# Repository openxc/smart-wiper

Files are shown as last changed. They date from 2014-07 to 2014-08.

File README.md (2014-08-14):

**Smart Wiper**
===============

The Smart Wiper project provides a simple way for collecting data on rain frequency and/or intensity. A 3D printed enclosure or 'box' houses an inertial measurement unit that can be attached to the windshield wiper. The device monitors the change in acceleration of the windshield wiper and use that as a surrogate for rain detection and intensity. 
The project contains:

* [Electronics Layout](https://github.com/openxc/smart-wiper/tree/master/Circuit_Design): The circuit diagram and all necessary electronics for the box
* [Arduino Firmware](https://github.com/openxc/smart-wiper/tree/master/Arduino): The arduino firmware that converts acceleration data into a generic wiper movement data
* [Android Project](https://github.com/openxc/smart-wiper/tree/master/Android): That communicates with the electronics box over bluetooth and provides a simple UI to display that
* [3D printed enclosure](https://github.com/openxc/smart-wiper/tree/master/CAD): CAD files for the box, for 3D printing the box

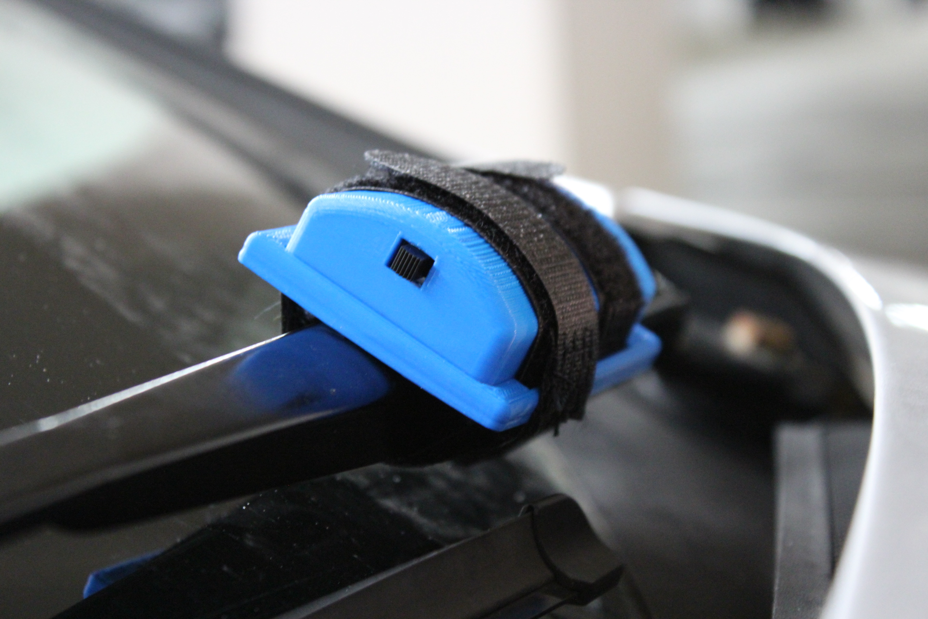
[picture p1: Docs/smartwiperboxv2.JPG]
smartwiperbox


## **Dependencies**

**Hardware**

* Bluetooth-compatible Android device
* Smart Wiper Box ([see 3D CAD files here](https://github.com/openxc/smart-wiper/tree/master/CAD))
* Electrical components ([see BOM here](https://github.com/openxc/smart-wiper/tree/master/BOMs))

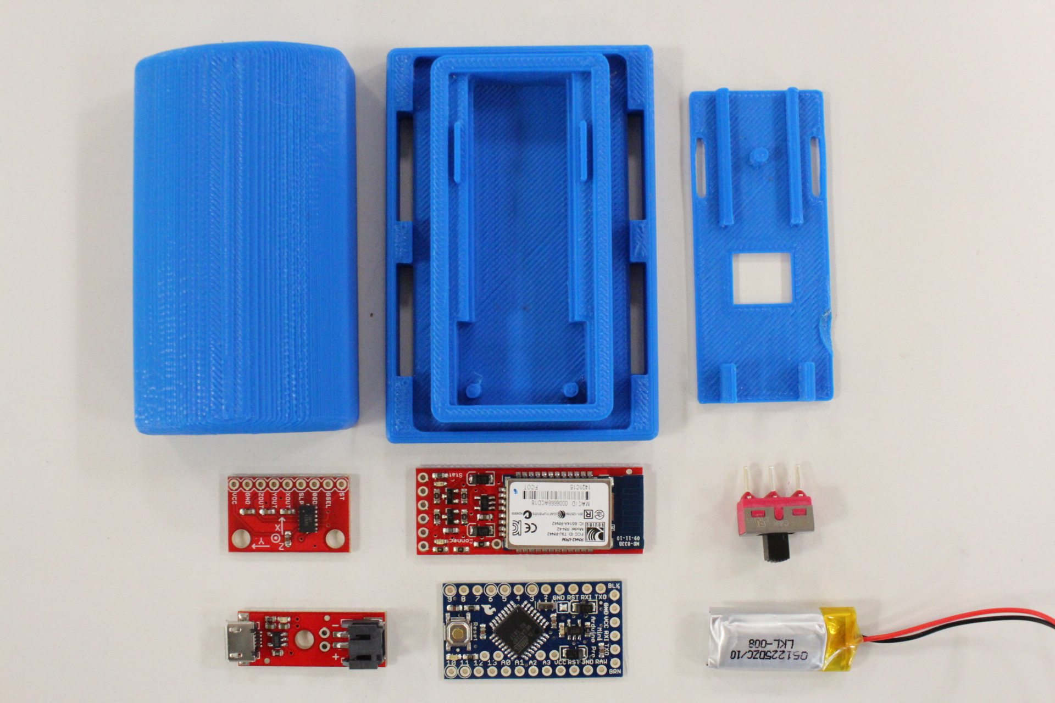
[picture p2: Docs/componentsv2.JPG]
hardware


**Software**

* Android SDK
* Android ADT/Eclipse
* Arduino IDE

## **Smart Wiper Hardware Assembly**

The Smart wiper box includes:
  - Arduino Pro Mini board 
  - Bluetooth-Module 
  - Triple-Axis Accelerometer
  - Li-ion battery 
  - USB-Charger 
  - 3D printed enclosure

The image below shows the overall circuit layout

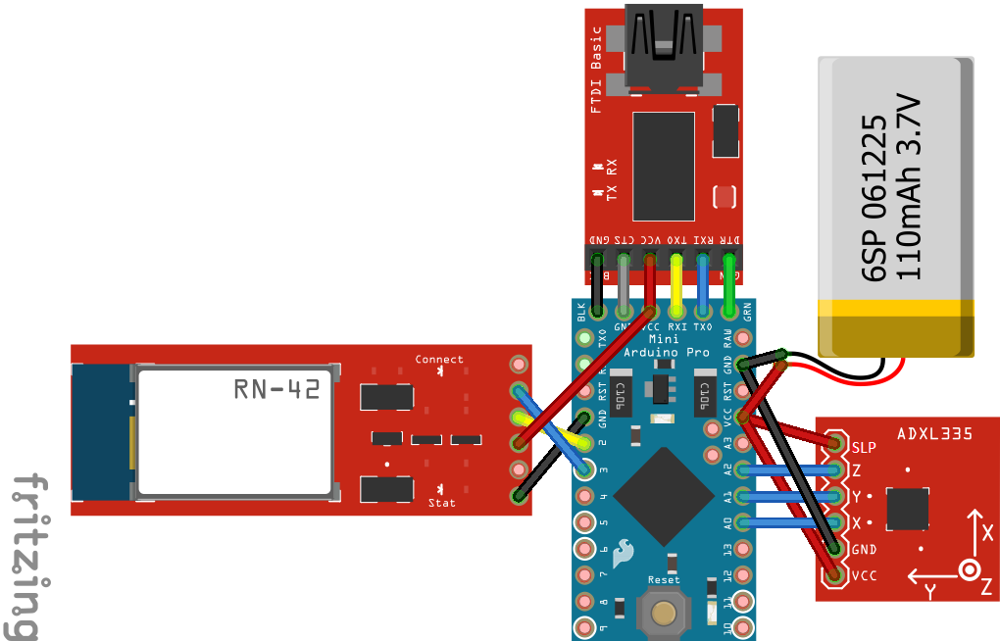
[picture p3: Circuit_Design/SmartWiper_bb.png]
Circuit


In order to assemble the box, follow these steps: 

1. Take a look at the electrical circuit design shown above to solder and connect all the electronic components. The length of the wires can be determined by how they stack up inside the enclosure. It is good practice to place all the parts and see how they are stacked and placed over each other as detailed between Step 2 and Step 6. 

2. Place the Bluetooth-module at the bottom of the [3D printed enclosure](https://github.com/openxc/smart-wiper/tree/master/CAD), the orientation of the Bluetooth-Module should be such that the pins on the module are next to the elevated holes sticking out from the bottom of the box for the Triple-Axis Accelerometer.
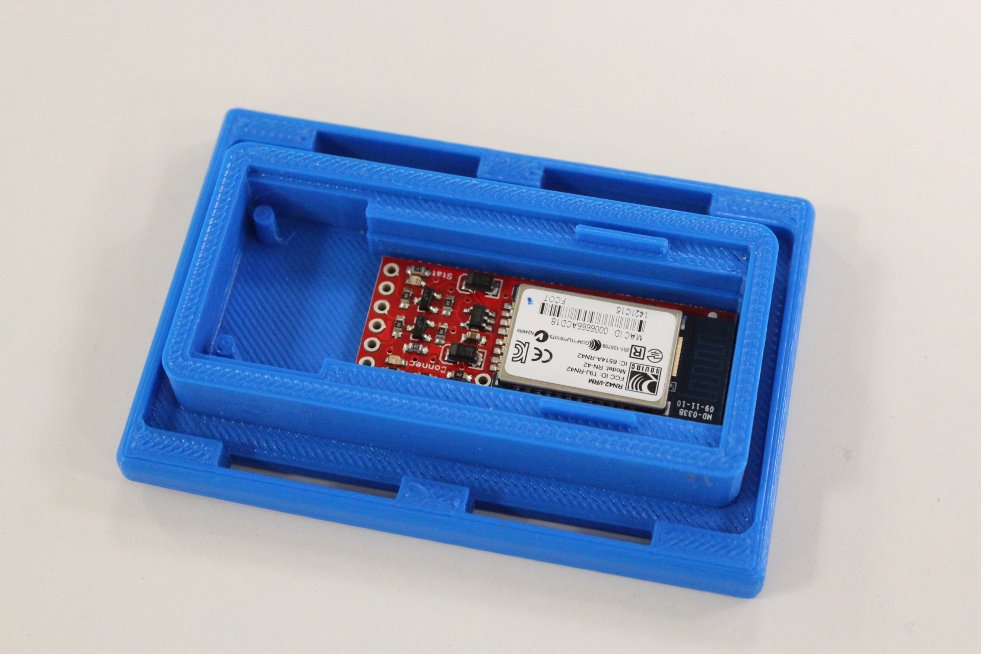
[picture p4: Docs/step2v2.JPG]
step2
   

3. Place the Arduino Pro Mini above the Bluetooth-Module such that it's front is facing up.
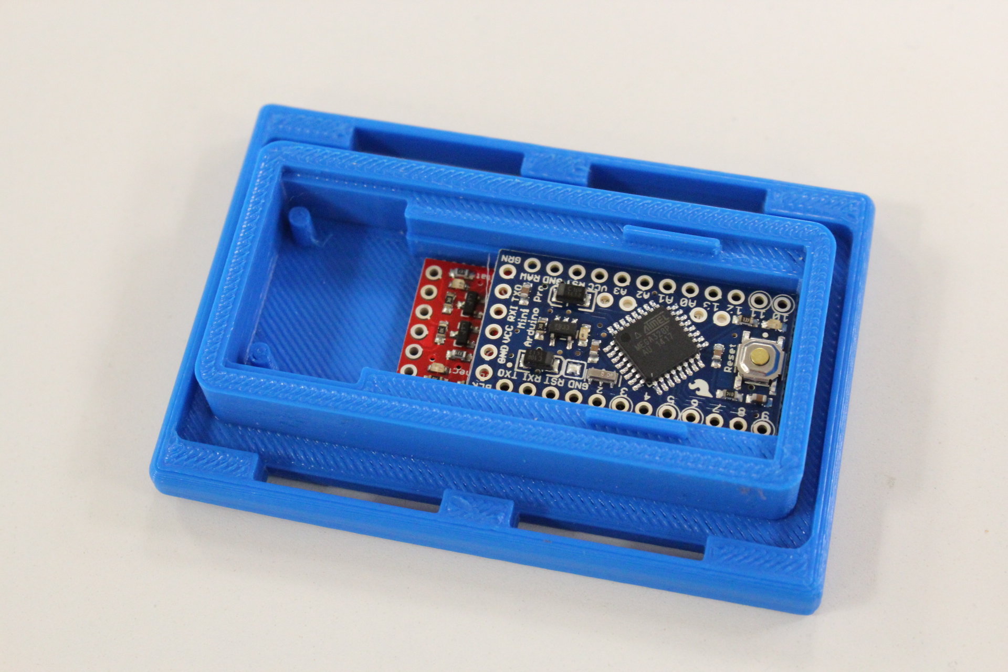
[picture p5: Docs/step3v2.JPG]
step3
      

4. Next place the Triple-Axis Accelerometer over the Arduino Pro Mini such that the end with holes sits right above the two pillars. Once the Accelerometer is placed, it can be held by the pillars.
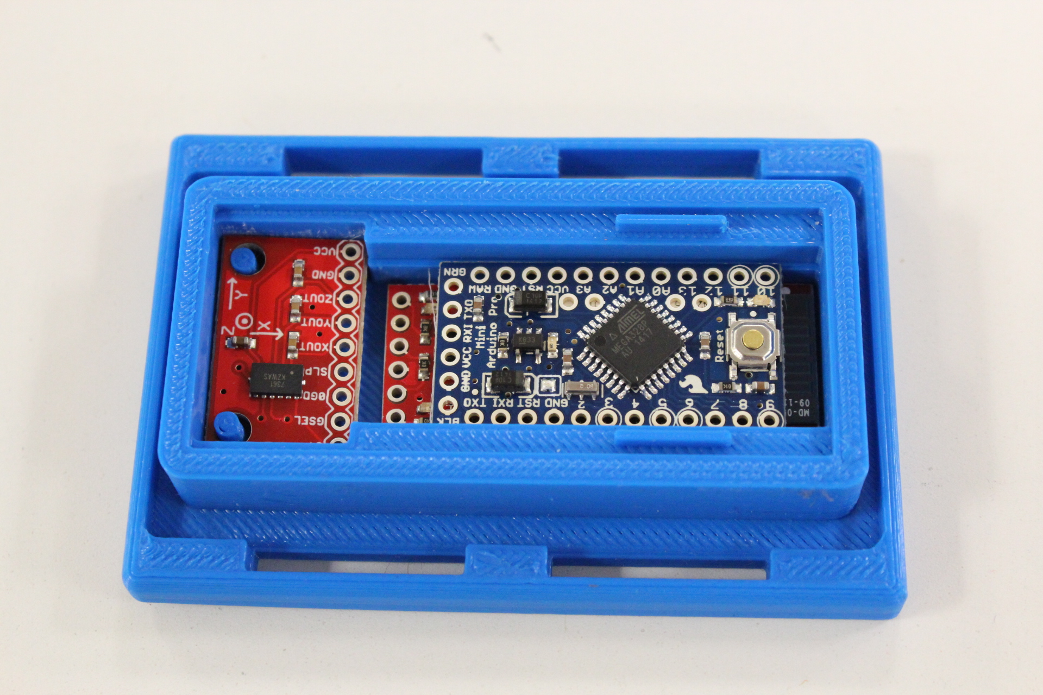
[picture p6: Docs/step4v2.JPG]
step4
     

5. Once the Triple-Axis Accelerometer is firmly secured grab the insert plate and place it over the Arduino Pro Mini and cover it.
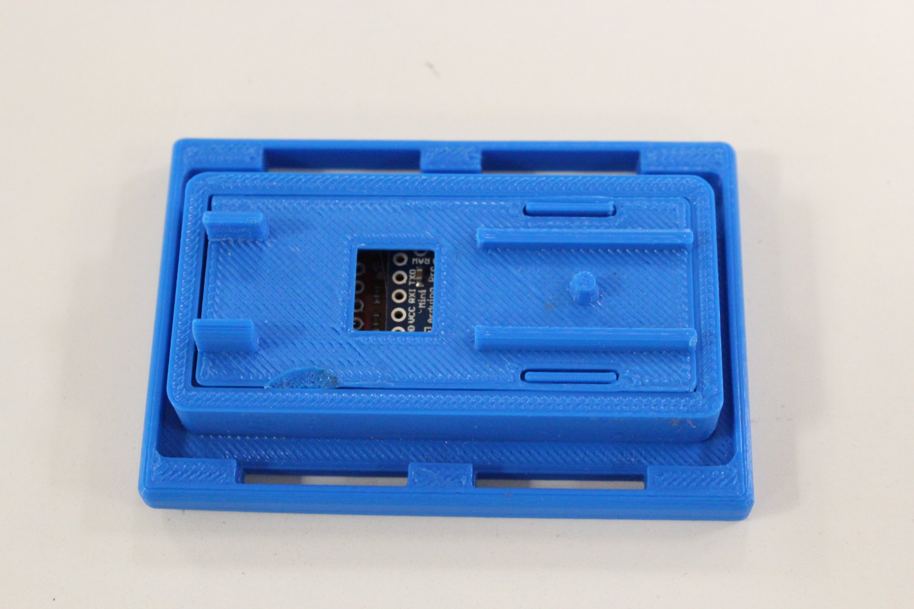
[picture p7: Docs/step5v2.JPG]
step5
  

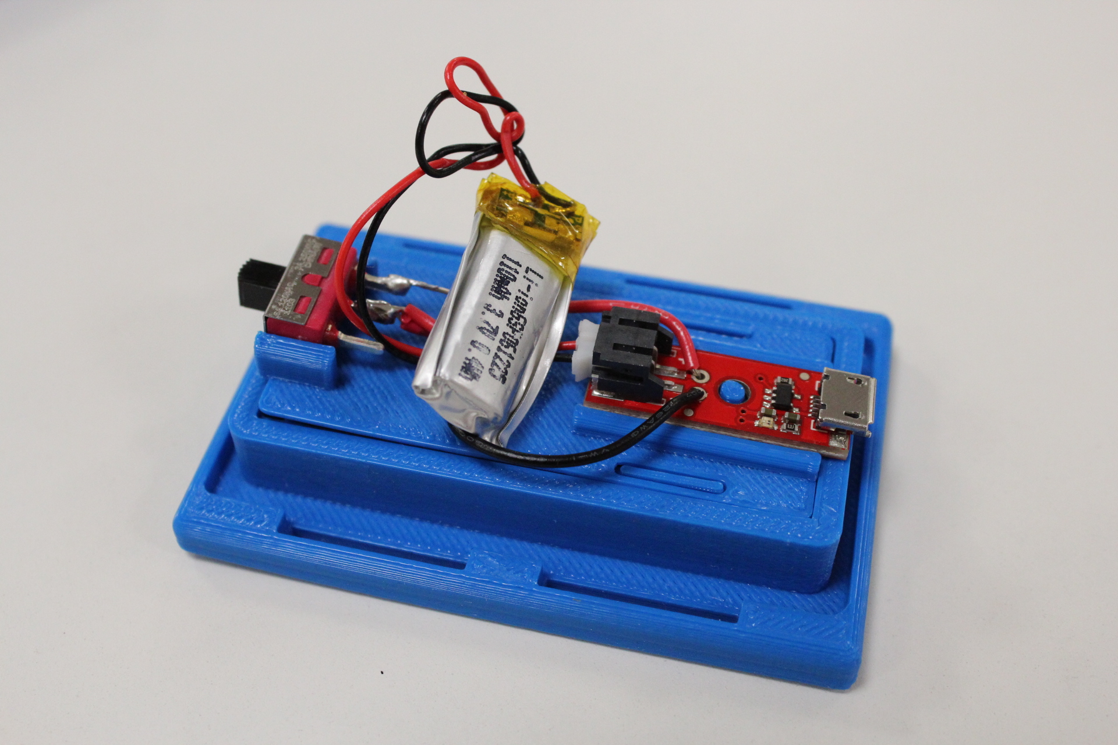
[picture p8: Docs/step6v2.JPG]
step6
6. Put the USB-Charger and the slide switch onto the insert plate and fix them, the female Micro-USB end of the charger should fit through the hole providing an easy way to charge the battery without taking the box apart.    
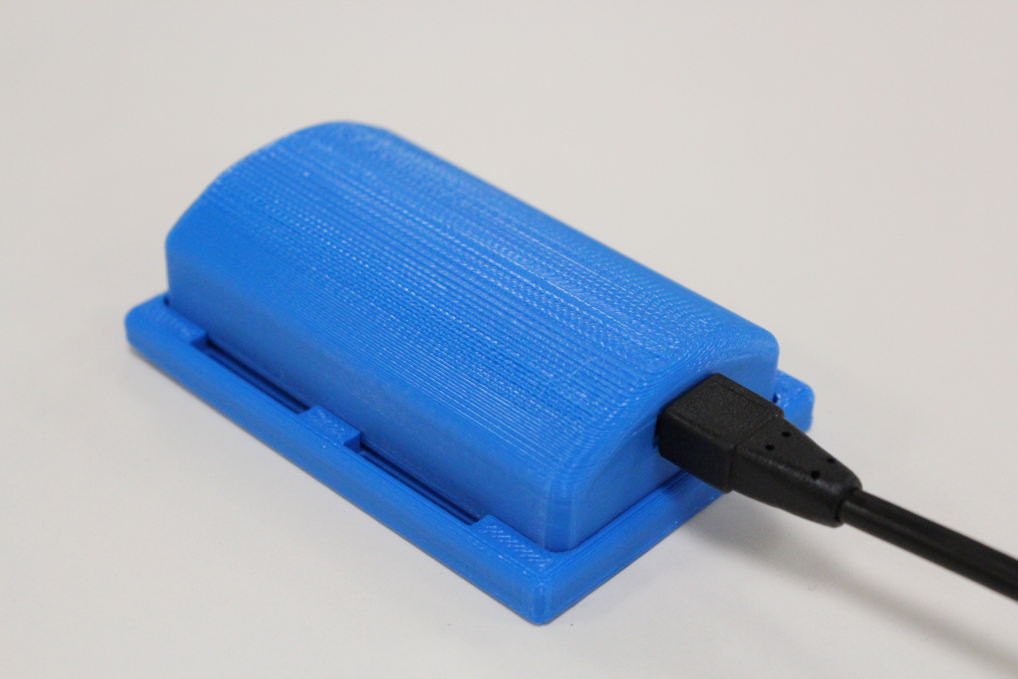
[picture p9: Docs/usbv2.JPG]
usb
  

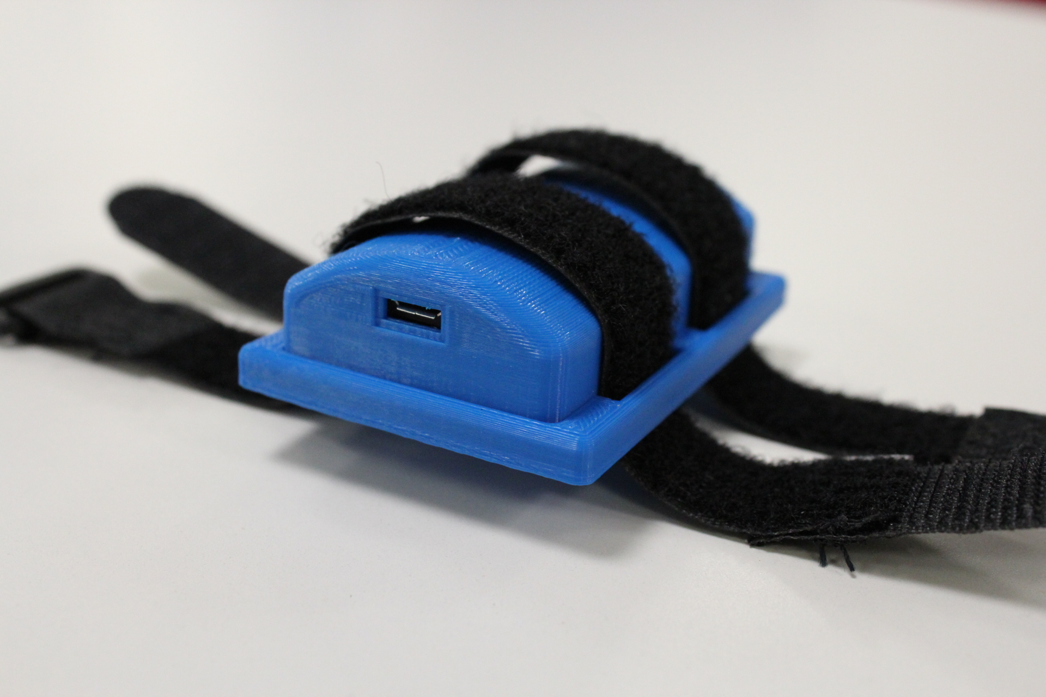
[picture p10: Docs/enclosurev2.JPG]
enclosure
7. Finally, put the Li-ion battery above the insert plate and fix the lid. Note: For a waterproof seal use the silicone adhesive around the lid. 

## **Arduino**

Once all the electronics are soldered and placed, we will upload the firmware on to the Arduino. To upload the firmware you need a FTDI cable, that has a standard male USB on its other end. More information can be found on the Arduino's website on how to upload a program on the [Arduino Pro Mini](http://arduino.cc/en/Guide/ArduinoProMini).

The Arduino firmware calculates and sends the information about the current state of the wiper to an Android device over Bluetooth. The Arduino receives the raw acceleration data from the Triple-Axis Accelerometer and calculates the variances along the three axes and determines whether the wiper is turned ON/OFF. More details on the algorithm and the scope is discussed in details [here](https://github.com/openxc/smart-wiper/tree/master/Arduino)

## **Android**

Note: The app best supports normal screens (4-6 inches) and large screens(7 inches) only. Before making any bluetooth connection to the smart-wiper-box, users should pair their wiper device with the mobile device using the android bluetooth settings section on the mobile device.

The primary purpose of the Android application is to get the sensor data from the Smart-Wiper Box via Bluetooth. In order to use the application, first go into the Bluetooth Setting of your android device, and pair it to the Arduino in the Smart-Wiper Box. 

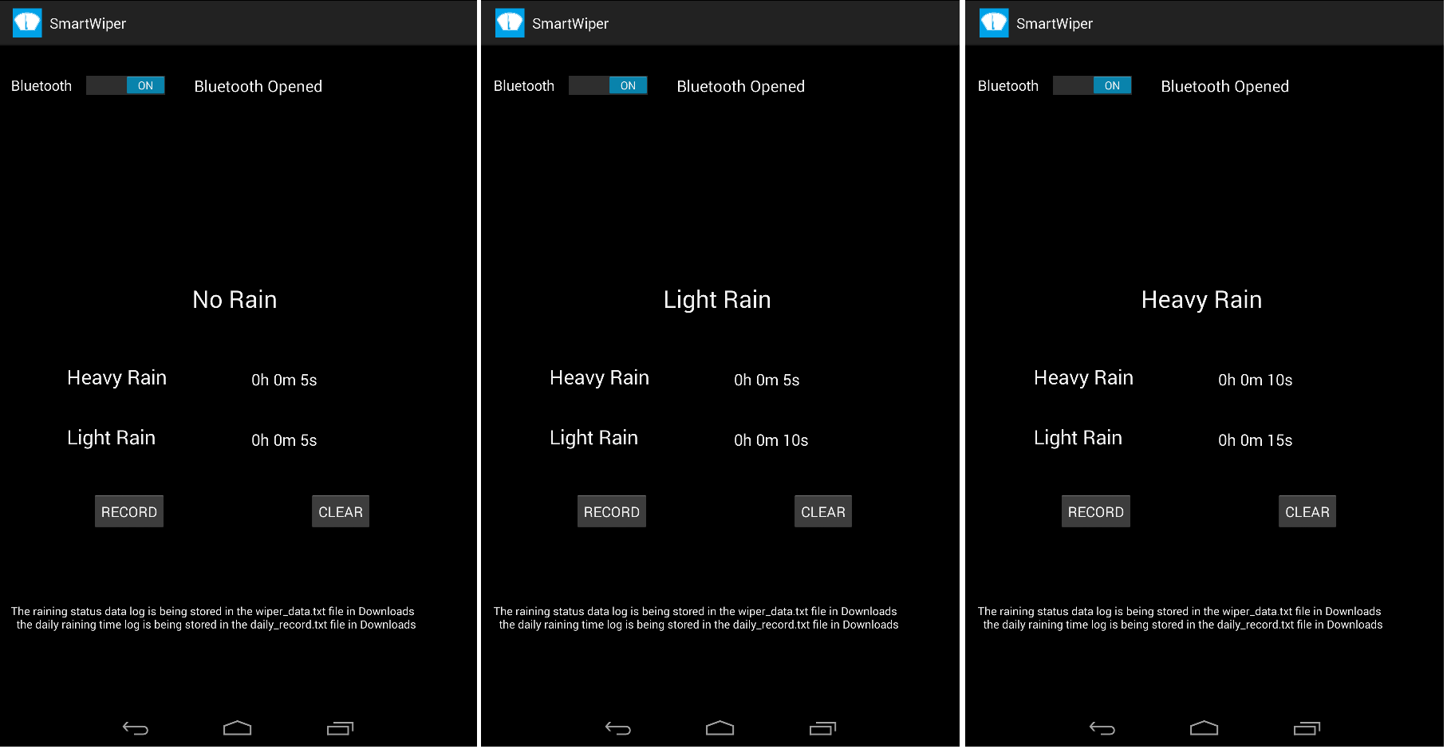
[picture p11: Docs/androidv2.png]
 

## **Installation Instruction**

For installation of the Smart-Wiper Box onto the wiper of your car, you can pass the velcro-straps through the slots on the side of box, and then fix the straps onto the wiper arm enclosing the wiper blade. It is important to orient the box such that the bottom of box goes face down, in contact with the wiper arm and the lid should face up. Ensure that the velcro strap has firmly secured the wiper box, and is not moving around. In our testing the box was attached roughly six inches from the bottom of the wiper, where it is hinged to the car. This location could change based on the shape and accesibility of the wiper, it was desirable to not place the wiper higher than six inches to avoid obstruction of sight while driving.

## **Testing Condition**

The Smart-Wiper Box was tested on the wiper of Ford Focus Titanium 2012 around Palo Alto, CA, at the speed range of 0-50 mph, under mixed road conditions containing highways, city roads and parking areas. It was also subjected to a veriety of different driving conditions, which varied from slow to rapid acceleration, braking and turning. In our tests we found that the Smart-Wiper Box was able to accurately estimate the wiper status. 

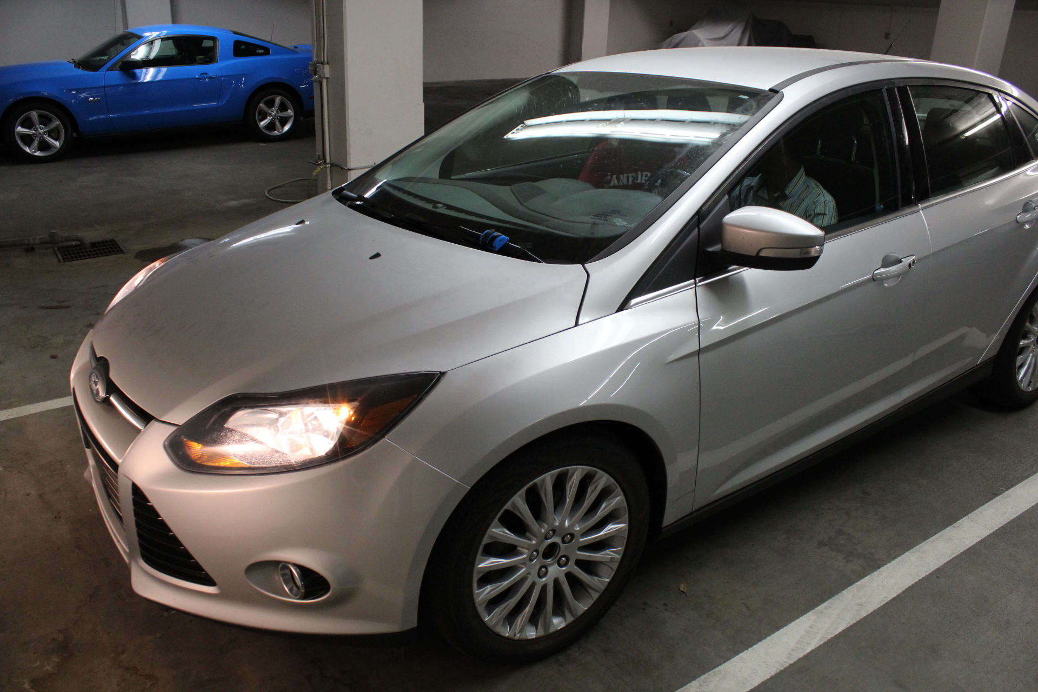
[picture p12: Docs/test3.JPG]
test3


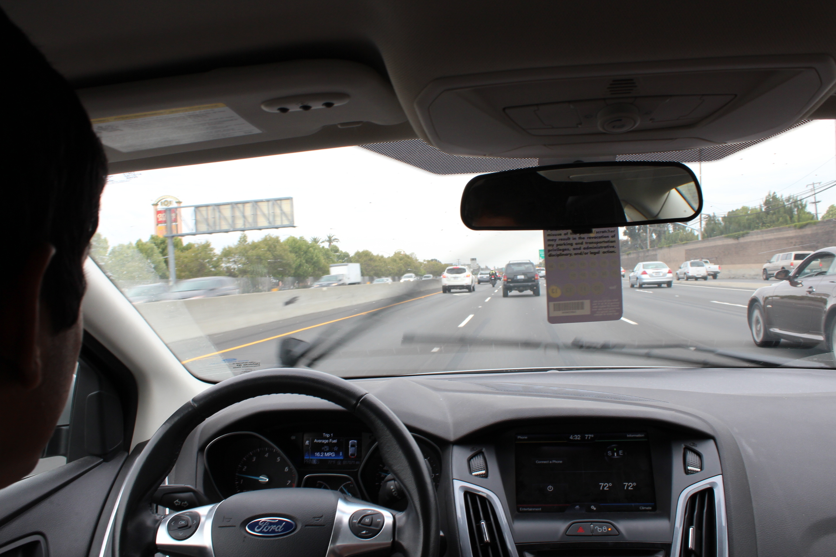
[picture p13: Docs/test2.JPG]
test2


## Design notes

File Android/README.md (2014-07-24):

**Android project for the Smart Wiper**
======================================

Update 07/21/2014

The updated application displays three raining status: "Heavy Rain", "Light Rain" and "No Rain" in the center.

The aggregated raining time of heavy rain and light rain displays separately on the screen. The raining time data for each status will be automatically recorded daily in "daily_record.txt" file in *Downloads* folder.

Users can record the current raining status and time data by pressing *RECORD* button. The data will be stored in "user_record.txt" file in *Downloads* folder.

Users can also clear the current raining time in screen by pressing *CLEAR* button.

______________________________________

The primary purpose of the Android application is to establish a Bluetooth connection with a previously paired Bluetooth-module, then listening for data being sent from the Smart-Wiper Box. As soon as the Bluetooth connection is established with the Smart-Wiper Box, it sends calculated wiper position data to the Android device. 

Note: In order to use the application,  you first need to pair the Smart-Wiper Box to the Android device. This can be done through the main Bluetooth Setting on the Android device.

Once the application is launched, toggle the *Bluetooth* switch and wait until the Bluetooth status says *Bluetooth Opened*. In order to check that a successful bluetooth connection was made, look for a green light on the Smart-Wiper Box. Once all connections are established Wiper Status data shows up in large text on the Android application. 

Note: If the Bluetooth status says *Bluetooth Device Found*, the android device has been paired to the device but a connection was not made.

In order to close the Bluetooth connection, turn off the *Bluetooth* switch. This stops all Bluetooth communication with the box. 

In order to view the logs that were saved, navigate to your device's *Downloads* folder. The data will be stored in a file called *wiper_data.txt*

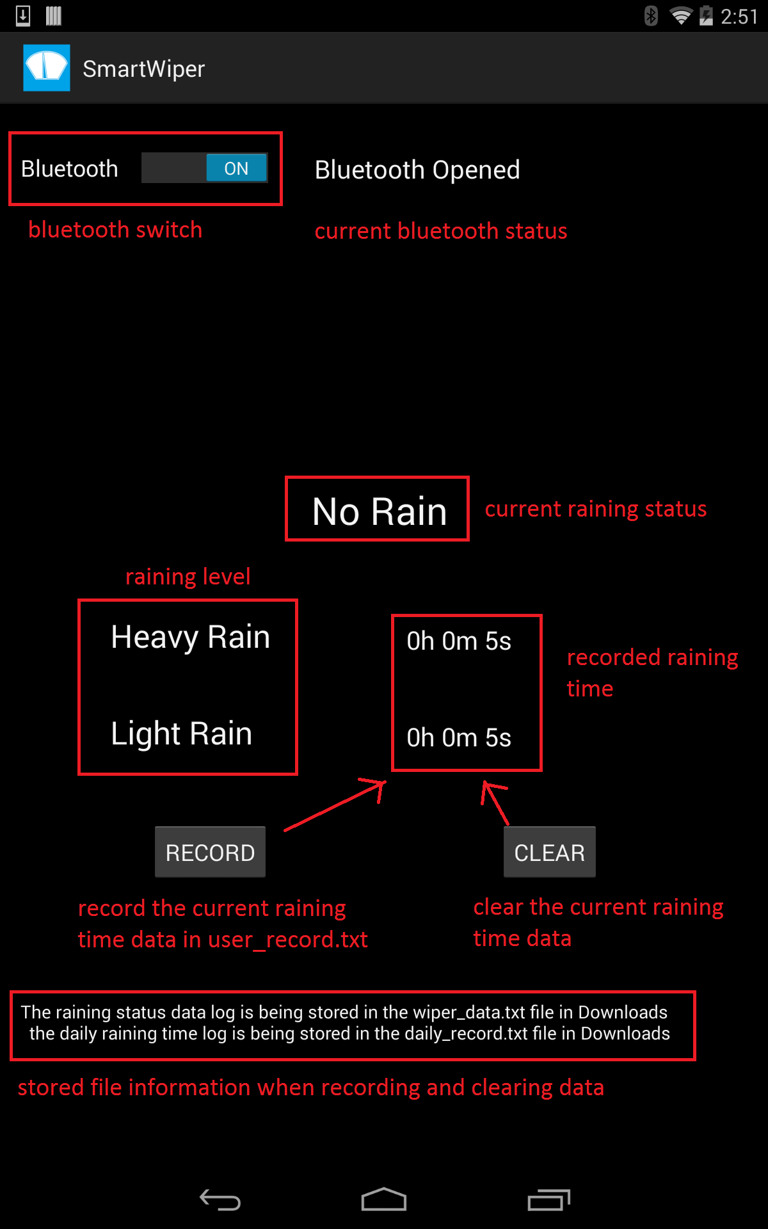
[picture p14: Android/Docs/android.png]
android


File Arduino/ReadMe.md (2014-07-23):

**Arduino firmware for the Smart Wiper**
===================================

The Arduino firmware calculates and sends the current wiper status to the Android device over Bluetooth. It measures the acceleration rates in X, Y, Z axes using a triple axis accelerometer, calculates the variance of acceleration rate X, Y, Z, and determine the state of the wiper based on the calculated value. The testing result demonstrated full functionality under regular driving condition, including highway driving and urban driving conditions. In the next version, new sensors might be added to the Wiper Box and could provide more data about wiper, and the data analysis would be more accurate by improving algorithm. 

**Algorithm Overview**

The accelerometer in the Smart-Wiper Box measures the instantaneous acceleration in three axes X, Y and Z ( refereed as a<sub>X</sub>, a<sub>Y</sub> and a<sub>Z</sub>). The directions of X, Y and Z are defined in the following picture:

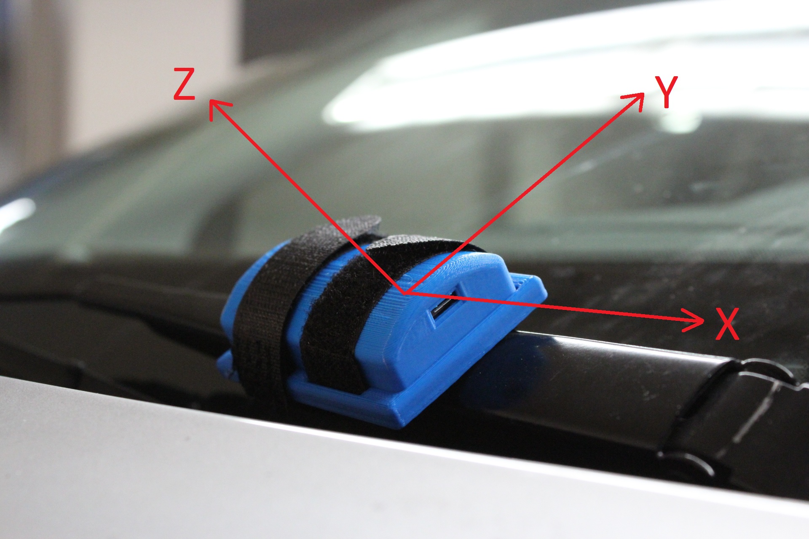
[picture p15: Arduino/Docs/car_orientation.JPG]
car_orientation


Now we define &theta; below:

&theta; = tan<sup>-1</sup>(a<sub>Y</sub> / a<sub>Z</sub>)

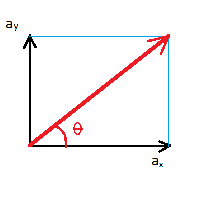
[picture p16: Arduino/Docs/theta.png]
theta


In order to distinguish the ON status of the wiper from OFF status, it is necessary to obtain the variance of &theta;, referred as Var(&theta;), and the variance of a<sub>Z</sub>, referred as Var(a<sub>Z</sub>). From our experiments (see the *Plot* below), clear pattern can be observed from the plot for Var(&theta;) and Var(a<sub>Z</sub>) between ON and OFF status. Therefore, an algorithm was developed to distinguish the status of the wiper and the raining condition can then be understood.

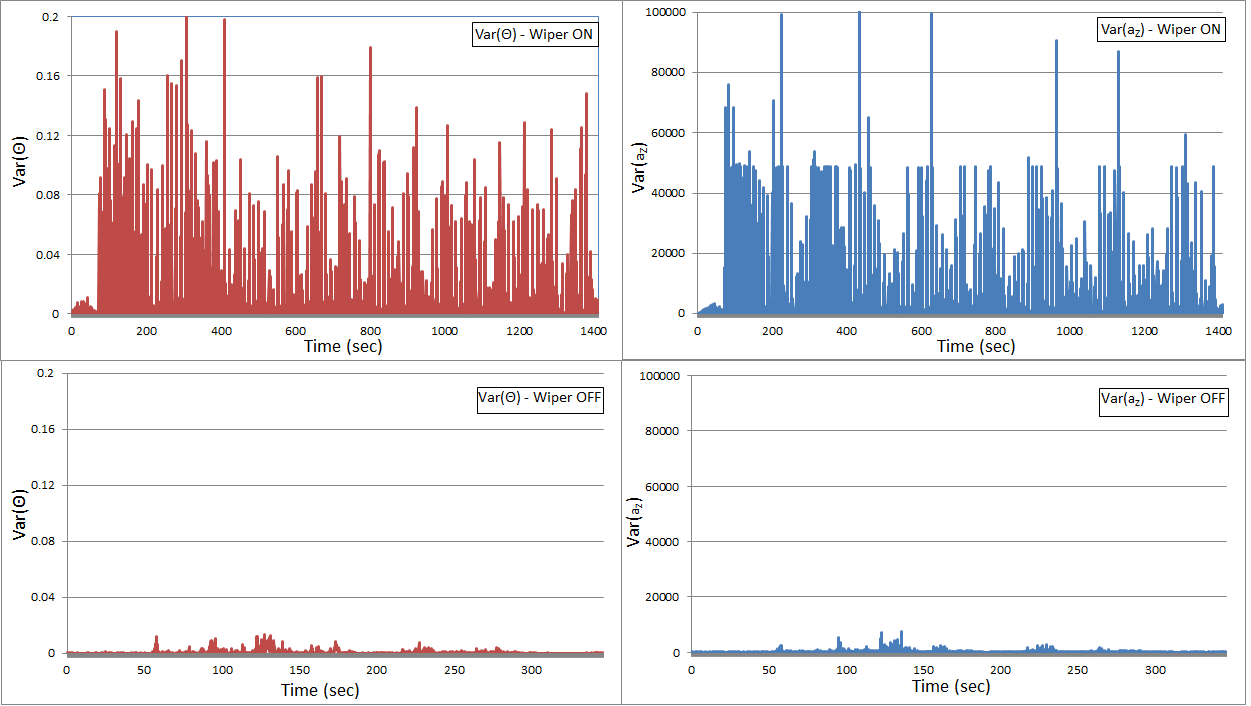
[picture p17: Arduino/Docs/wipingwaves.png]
Wiping Waves


Mathematically the variance can be calculated in the following steps: 

1. Find average values of &theta; and a<sub>Z</sub> (*In order to get the average values, the microcontroller sums up &theta in the first 50 data points (1 sec) when receiving data and calculates the average values*)

  equ4       
  equ5

2. Find the variance of &theta;

  equ2

3. Find the variance of a<sub>Z</sub>

  equ3 

The algorithm is explained as the followings: 

1. If any of Var(&theta;) and Var(a<sub>Z</sub>) are *lower* than the respective threshold value(Th) in the period of 5 seconds, the microcontroller will send **No Rain** signal to Android application over Bluetooth.

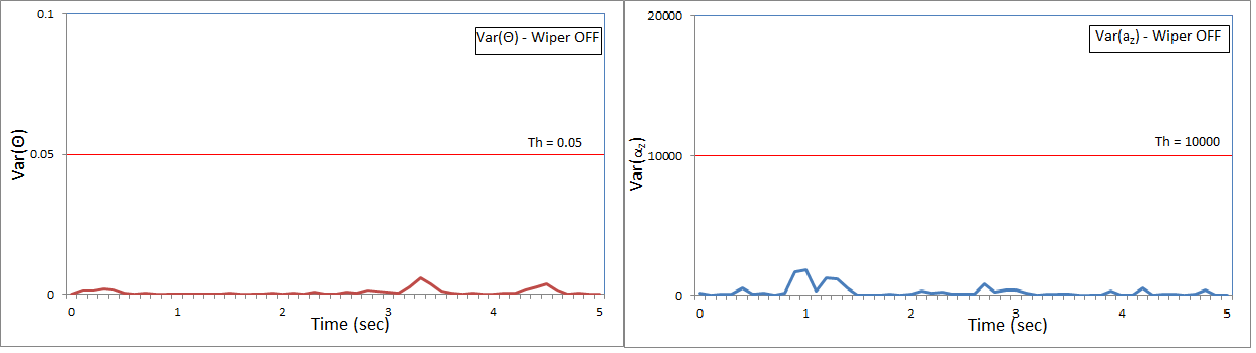
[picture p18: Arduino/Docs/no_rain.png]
no rain
  

2. If both Var(&theta;) and Var(a<sub>Z</sub>) are *higher* than the respective threshold value(Th) for *1-8 points* (1-2 peaks) the period of 5 seconds, the microcontroller will send **Light Rain** signal to Android application. 

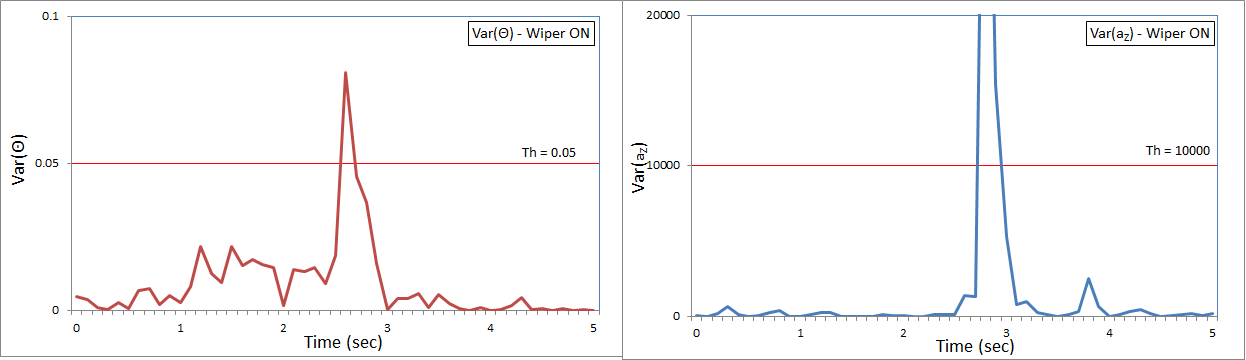
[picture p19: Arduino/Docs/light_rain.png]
light rain
  

3. if both Var(&theta;) and Var(a<sub>Z</sub>) are *higher* than the respective threshold value(Th) for *more than 8 points* (3 peaks or more) in the period of 5 seconds, the microcontroller will send **Heavy Rain** signal to Android application. 

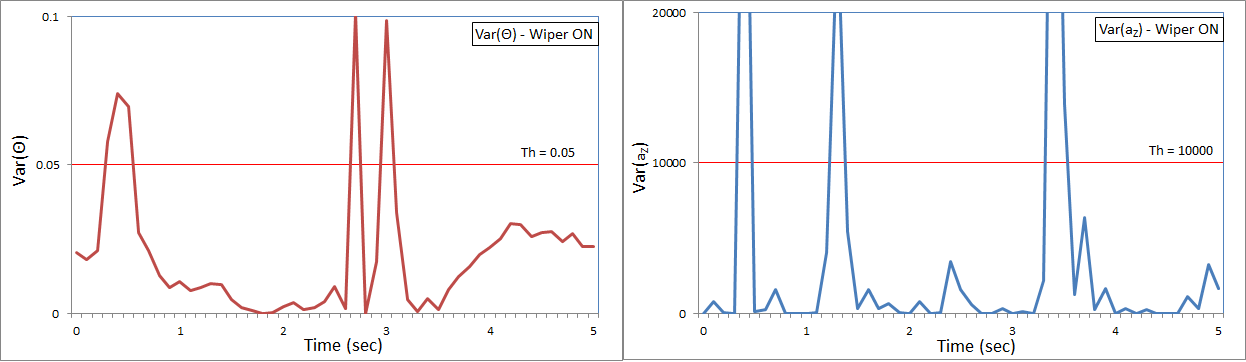
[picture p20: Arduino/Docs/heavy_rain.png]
heavy rain


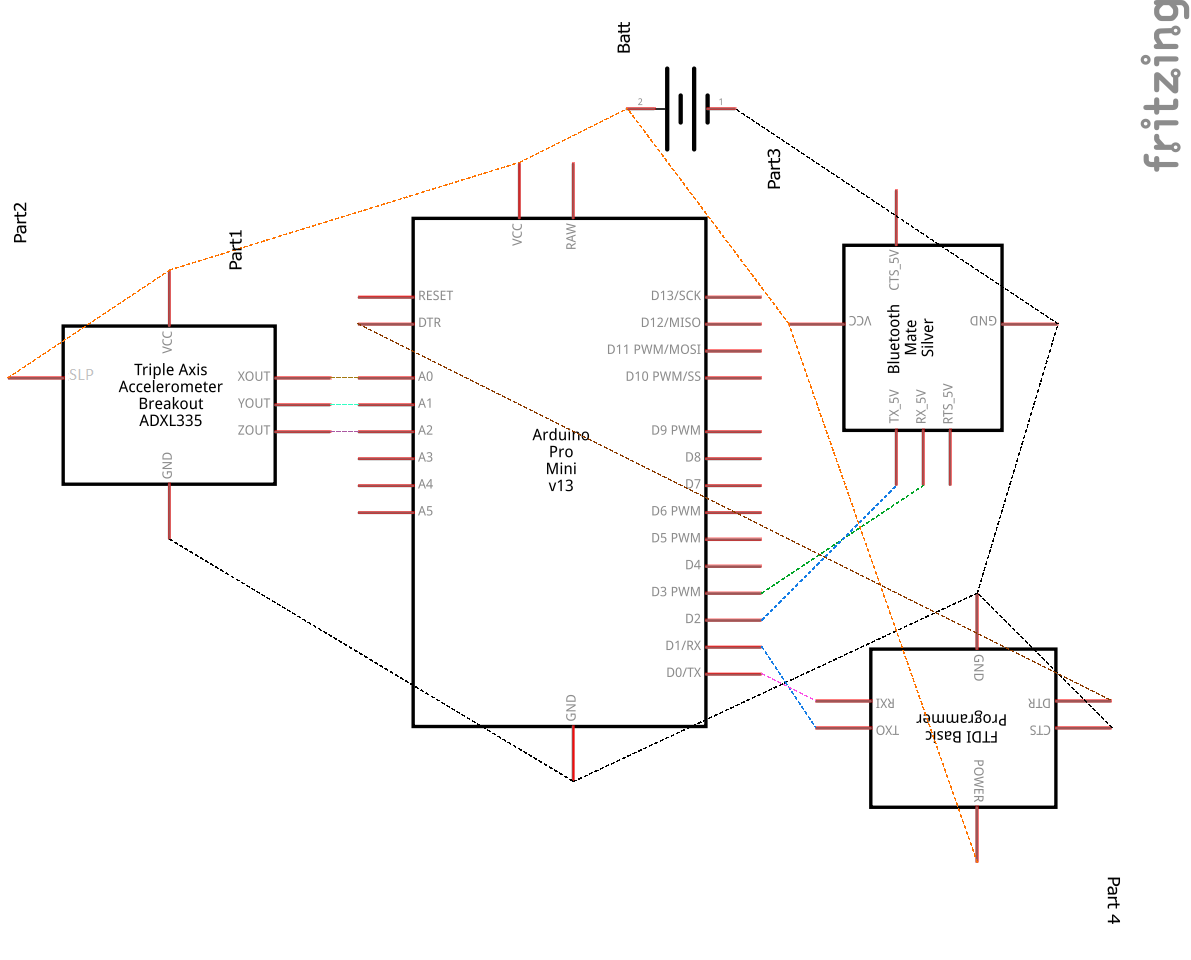
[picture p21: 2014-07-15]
Circuit_Design/SmartWiper_schem.png

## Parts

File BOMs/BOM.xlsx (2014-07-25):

Item | Quantity | Order Link | Unit Price | Subtotal | Notes
Arduino Pro Mini 328 - 3.3V/8MHz | 1 | https://www.sparkfun.com/products/11114 | 9.95 | 9.95
Polymer Lithium Ion Battery - 110mAh | 1 | https://www.sparkfun.com/products/731 | 4.95 | 4.95
FTDI Basic Breakout - 3.3V | 1 | https://www.sparkfun.com/products/9873 | 14.95 | 14.95
Bluetooth Modem - BlueSMiRF Silver | 1 | https://www.sparkfun.com/products/12577 | 39.95 | 39.95
Triple Axis Accelerometer MMA7361 | 1 | https://www.sparkfun.com/products/9652 | 11.95 | 11.95
Arduino Stackable Header - 6 Pin | 3 | https://www.sparkfun.com/products/9280 | 0.5 | 1.5
LiPo Charger Basic - Micro-USB | 1 | https://www.sparkfun.com/products/10217 | 7.95 | 7.95
Permatex 80050 Clear RTV Silicone Adhesive Sealant, 3 oz. | 1 | http://www.amazon.com/gp/product/B0002UEPVI | 4.39 | 4.39
Velcro Sticky Back | 1 | http://www.amazon.com/VELCRO-U-S-A-Sticky-Black-VEK91137/dp/B000GRBEK2 | 26.04 | 26.04
Slide Switch | 1 | https://www.sparkfun.com/products/9609 | 0.75 | 0.75
Jumper Wires - Connected 6" (M/M, 20 pack) | 1 | https://www.sparkfun.com/products/12795 | 1.95 | 1.95
 |  |  | Total Cost: | 124.33
Equipment | Quantity | Usage
MakerBot Replicator 2 Desktop 3D Printer w/ PLA printing material | 1 | 3d printing
Soldering Station w/ solder lead | 1 | soldering
Solder Vacuum | 1 | desoldering
Multimeter | 1 | circuit testing

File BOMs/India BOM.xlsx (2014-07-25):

Item | Quantity | Order Link | Unit Price
Arduino Pro Mini 328 - 3.3V/8MHz | 1 | http://www.protocentral.com/arduino-boards/30-arduino-pro-mini-33v.html | Rs.999
Polymer Lithium Ion Battery - 500mAh | 1 | http://www.protocentral.com/batteries/589-polymer-lithium-ion-battery-500mah.html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 | Rs. 699
FTDI Basic Breakout - 3.3V | 1 | http://www.protocentral.com/arduino-boards/29-ftdi-basic-breakout-33v.html?search_query=ftdi&results=39 | Rs. 1,299
Bluetooth Modem - BlueSMiRF Silver | 1 | http://shop.logicinside.net/product/4003/ | Rs. 3,650
Triple Axis Accelerometer MMA7361 | 1 | http://shop.logicinside.net/product/triple-axis-accelerometer-breakout-mma7361/ | Rs. 990
Arduino Stackable Header - 6 Pin | 3 | http://www.protocentral.com/prototyping/159-arduino-stackable-header-kit.html?search_query=header&results=113 | Rs.109
LiPo Charger Basic - Micro-USB | 1 | http://www.tenettech.com/product/1404/lipo-charger-basic-micro-usb | Rs. 823.00
Permatex 80050 Clear RTV Silicone Adhesive Sealant, 3 oz. | 1 | http://www.amazon.com/gp/product/B0002UEPVI
Velcro Sticky Back | 1 | http://www.amazon.com/VELCRO-U-S-A-Sticky-Black-VEK91137/dp/B000GRBEK2
Slide switch | 1 | http://www.amazon.com/SS12D00G3-Position-Panel-Vertical-Switch/dp/B007QAJUUS?s=industrial
Breadboard Jumper Wire Pack | 1 | http://www.protocentral.com/cablewire/170-breadboard-jumper-wire-pack-.html?search_query=jumper&results=37 | Rs. 199
 |  |  | Total Cost:
Equipment | Quantity | Usage
MakerBot Replicator 2 Desktop 3D Printer w/ PLA printing material | 1 | 3d printing
Soldering Station w/ solder lead | 1 | soldering
Solder Vacuum | 1 | desoldering
Multimeter | 1 | circuit testing

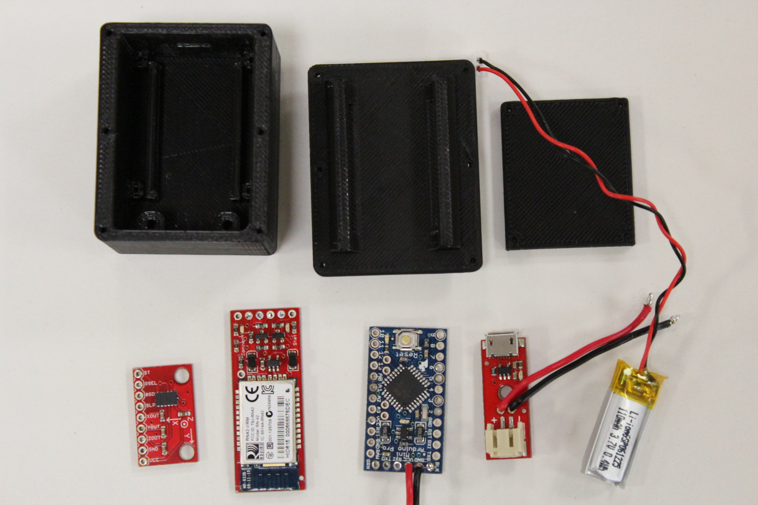
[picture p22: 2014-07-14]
Docs/components.JPG

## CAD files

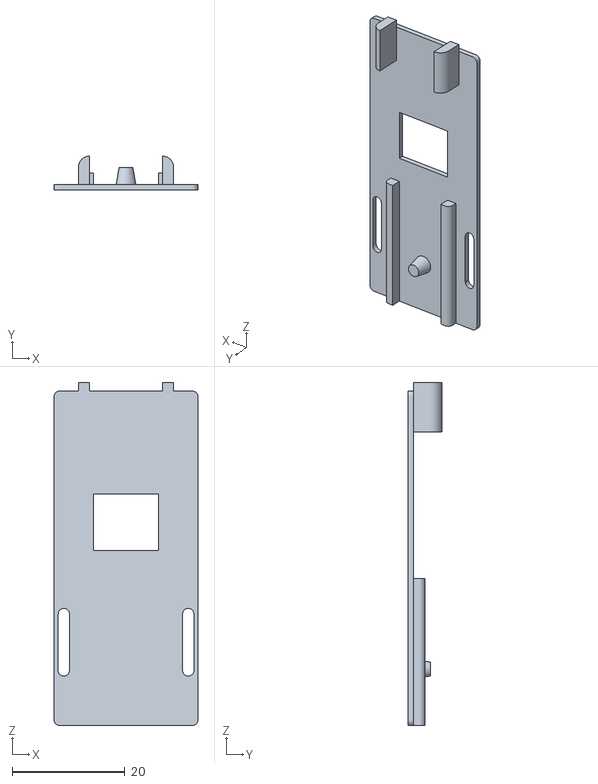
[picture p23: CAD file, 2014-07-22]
CAD/INSERT_ver2.stl
25.5 x 6.00 x 60.8

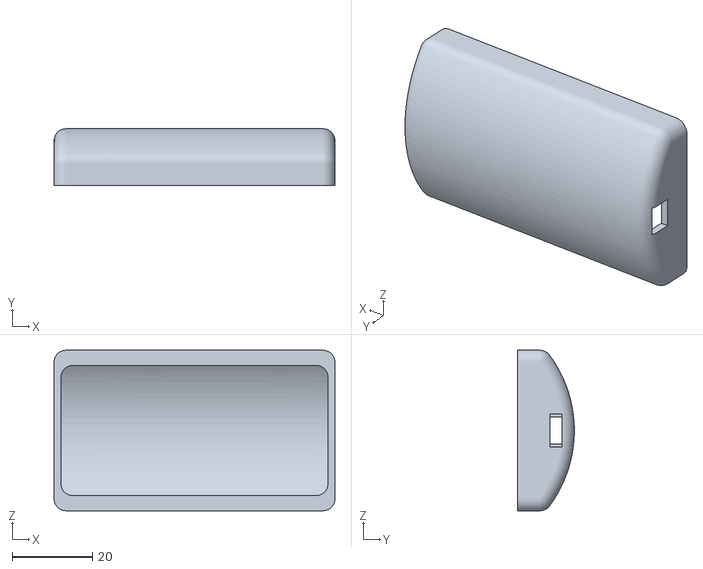
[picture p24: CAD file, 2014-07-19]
CAD/LID_ver2.stl
70.0 x 14.1 x 40.0

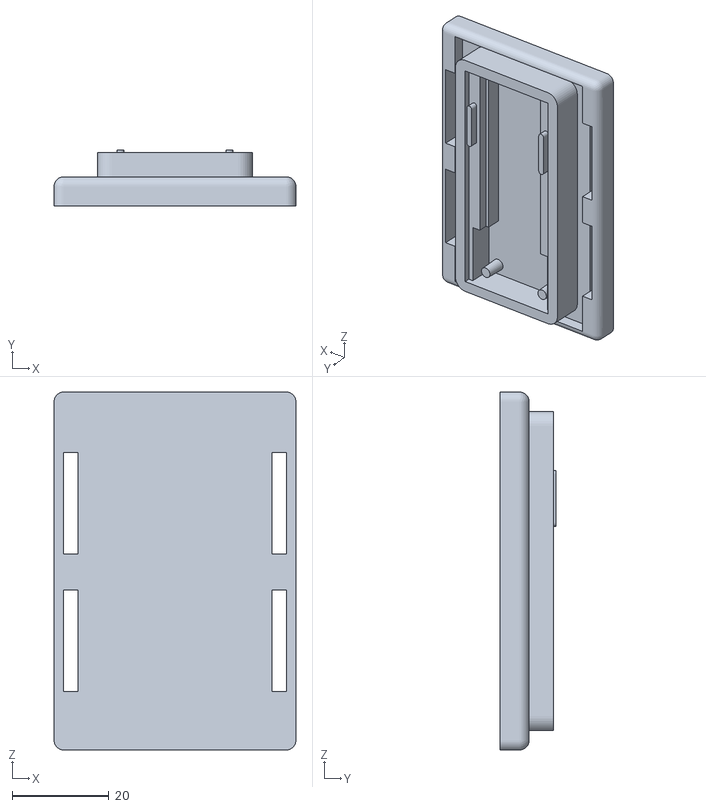
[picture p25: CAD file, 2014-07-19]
CAD/BOX_ver2.stl
50.0 x 11.5 x 74.0

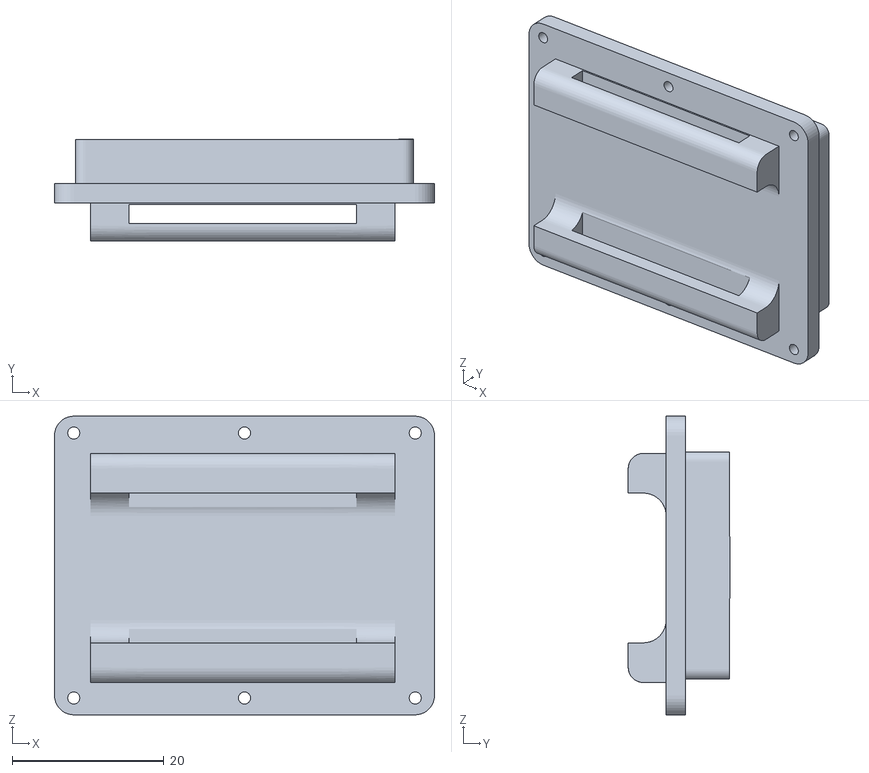
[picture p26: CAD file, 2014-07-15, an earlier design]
CAD/LID.stl
50.1 x 13.4 x 39.4

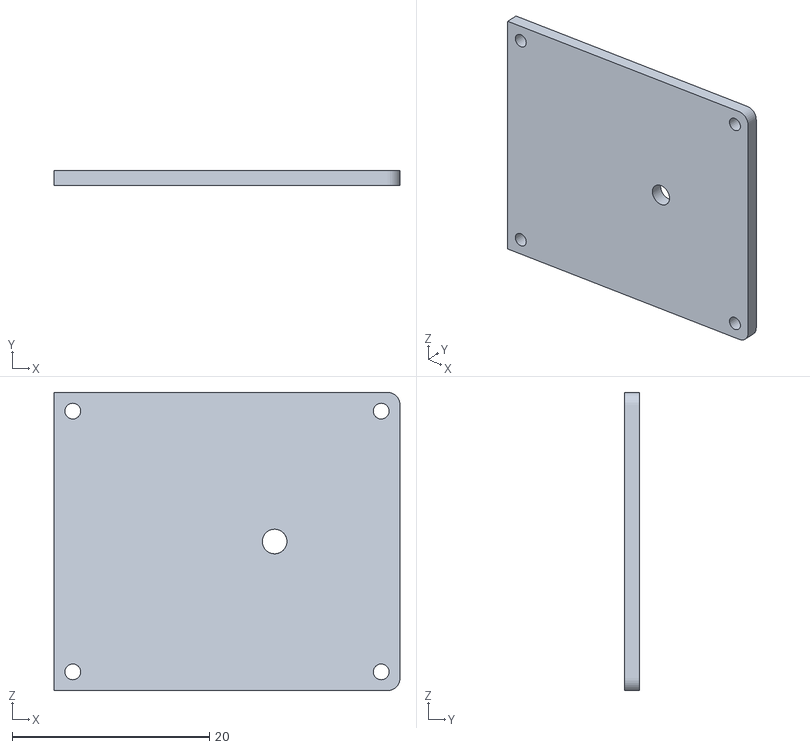
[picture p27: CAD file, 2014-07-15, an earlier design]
CAD/INSERT.stl
35.1 x 1.54 x 30.2

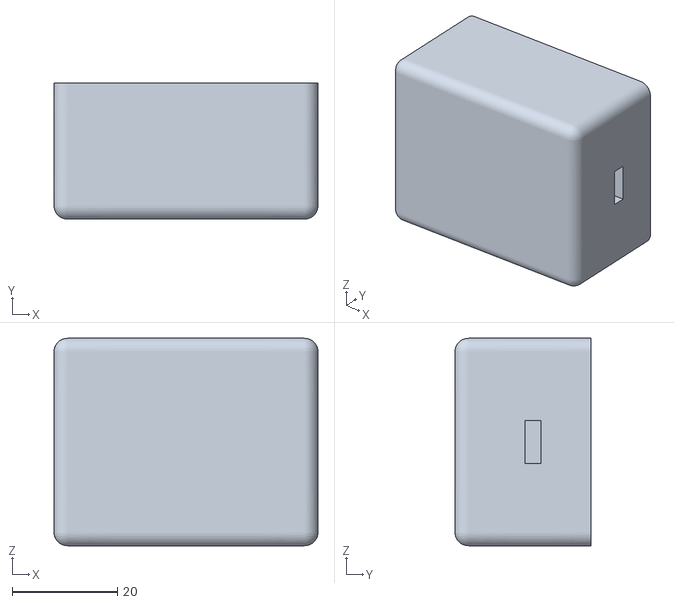
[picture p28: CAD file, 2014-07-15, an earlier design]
CAD/BOX.stl
50.1 x 25.8 x 39.4

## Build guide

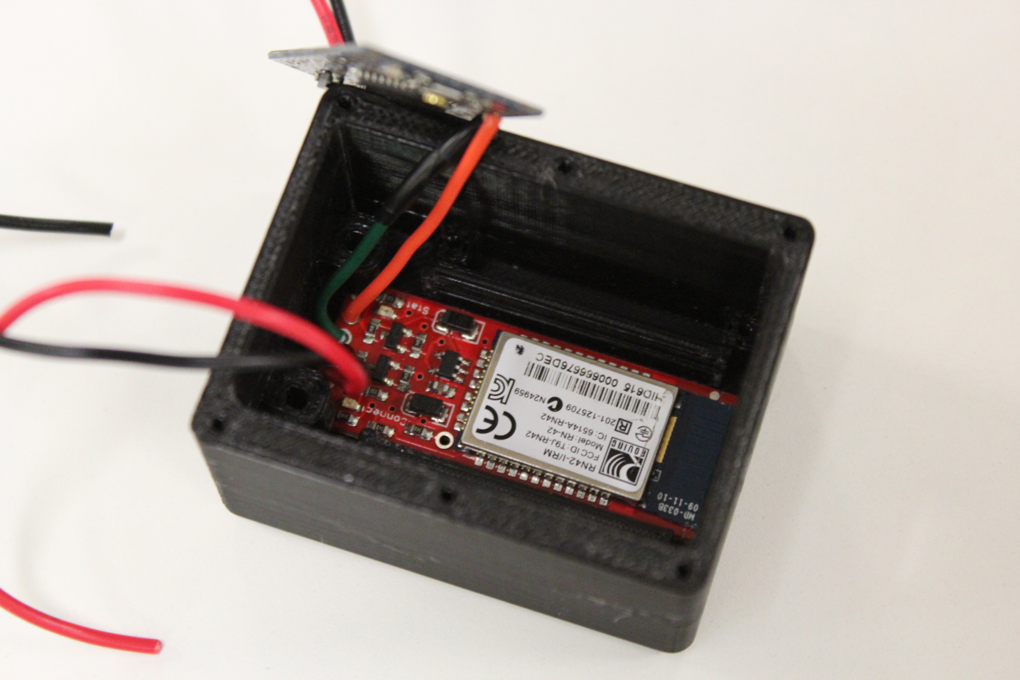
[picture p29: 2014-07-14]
Docs/step2.JPG

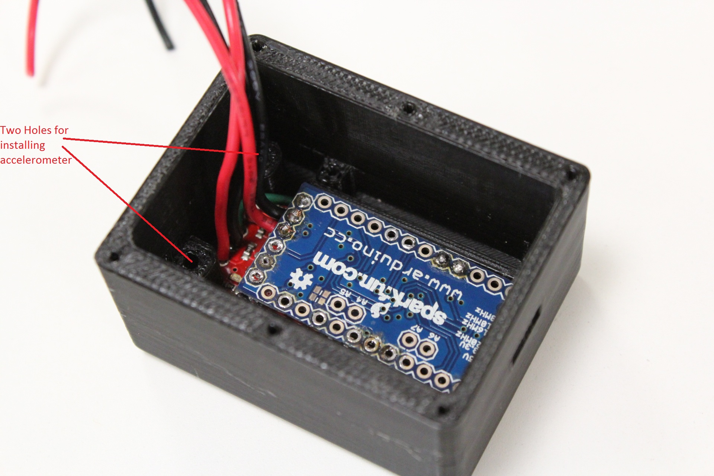
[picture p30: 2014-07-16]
Docs/step3.JPG

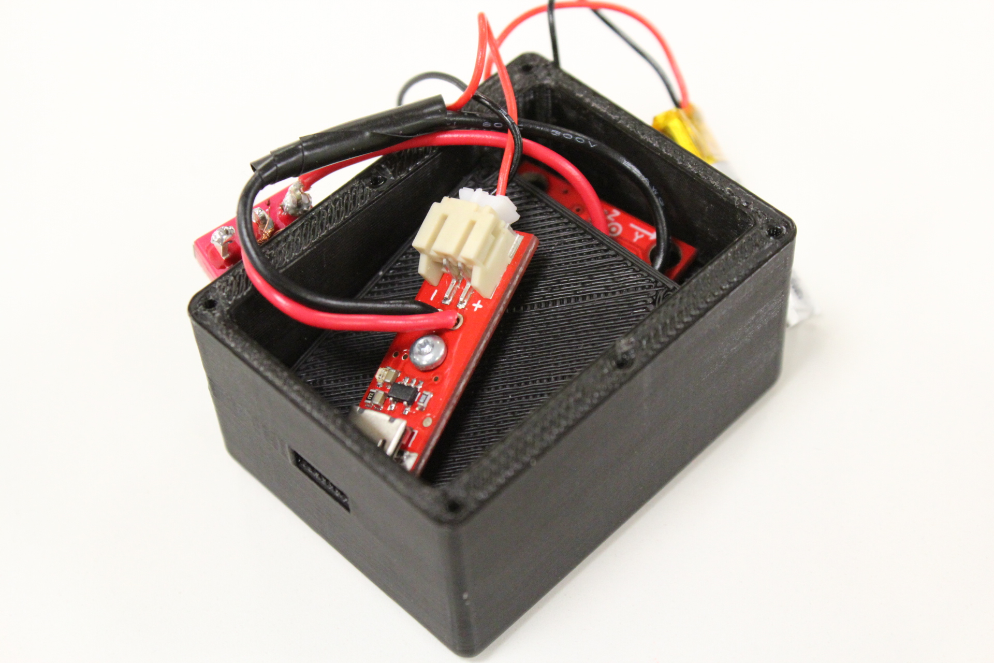
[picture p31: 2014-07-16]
Docs/step4.JPG

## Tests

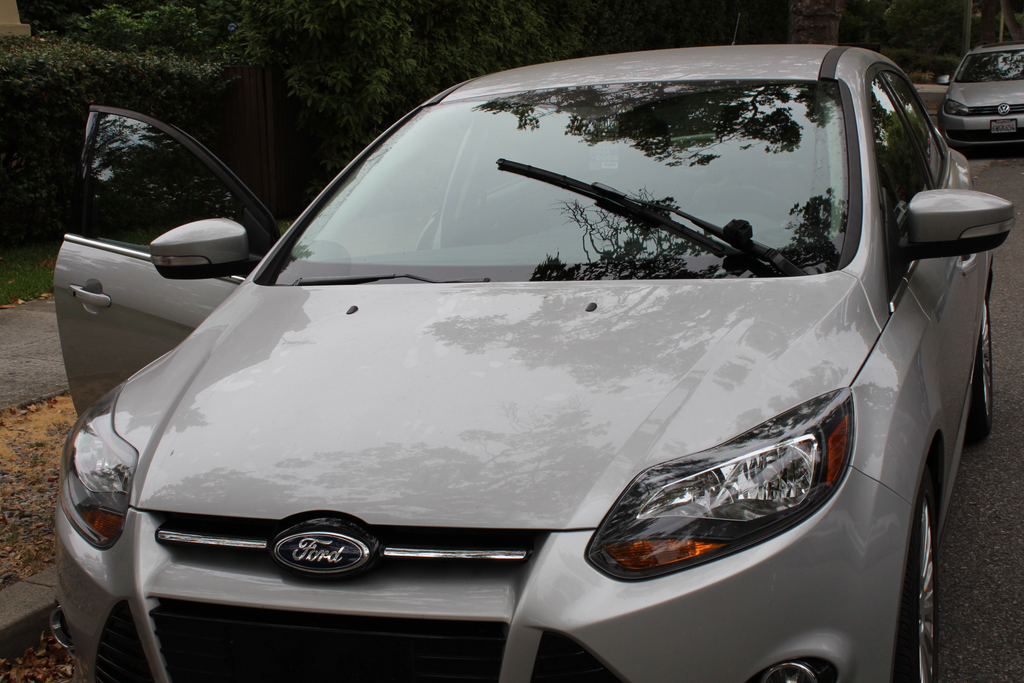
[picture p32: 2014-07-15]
Docs/test1.JPG

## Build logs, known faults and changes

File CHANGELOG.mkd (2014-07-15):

# Smart-Wiper

## v1.0

* Initial release

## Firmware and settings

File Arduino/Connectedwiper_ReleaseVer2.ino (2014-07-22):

/** 
 * Authors: Ford Silicon Valley Lab
 *
 * This code is used for the connectedwiper project, receives data from triple axis accelerometer
 * and tells if the wiper is wiping or not. It also recognizes the speed level of the wiper.
 */
 
#include <SoftwareSerial.h>
#include "math.h"

#define PERIOD 5000 // milliseconds for each measurement
#define THRESHOLD_XY 0.05 // threshold of varAngle value between wiping/non-wiping states
#define THRESHOLD_Z 10000 // threshold of varZ value between wiping/non-wiping states
#define COUNT_THRESHOLD 8 // threshold of counting peaks of varXY and varZ between heavy rain and light rain 

int axisX = 0; // measures value of X axis
int axisY = 0; // measures value of Y axis
int axisZ = 0; // measures value of Z axis
long sumX = 0; // sums the value of X axis for calculating the refX
long sumY = 0; // sums the value of Y axis for calculating the refY
long sumZ = 0; // sums the value of Z axis for calculating the refZ
long refX = 0; // measures the reference value for X axis
long refY = 0; // measures the reference value for Y axis
long refZ = 0; // measures the reference value for Z axis
double angle; // measures the atan2(axisX, axisY)
double refAngle; // measures the reference value of atan2(axisX, axisY)
double varAngle; // measures the variance of angle with respect to refAngle
long varZ = 0; // measures the variance of axisZ with respect to refZ
int countVarXY = 0; // measures how many times the value of varAngle is beyond THRESHOLD value
int countVarZ = 0; // counts the number of lowest peak of Z axis which is below the MIN_Z value
long startTime = 0; // measures the start time in ms for each loop function
int bluetoothTx = 4; // TX-0 pin of bluetooth to Arduino D2
int bluetoothRx = 5; // RX-1 pin of bluetooth to Arduino D3 
SoftwareSerial bluetooth(bluetoothTx, bluetoothRx); // uses SoftwareSerial to send data via bluetooth

void setup()
{
 // start serial port and bluetooth port at 9600 bps:
 Serial.begin(9600);
 bluetooth.begin(9600);
}

void loop()
{
  // initialization
  axisY = 0;
  axisX = 0;
  axisZ = 0;
  angle = 0.0;
  varAngle = 0.0;
  varZ = 0.0;
  countVarXY = 0;
  countVarZ = 0;
  startTime = millis();
  
  // measures the reference values
  sumX = 0;
  sumY = 0;
  sumZ = 0;
  for (int i = 0; i < 50; i++) {
   axisX = analogRead(A0);
   delay(5);
   axisY = analogRead(A1);
   delay(5);
   axisZ = analogRead(A2);
   sumX = sumX + axisX;
   sumY = sumY + axisY;
   sumZ = sumZ + axisZ;
  }
  refX = sumX/100;
  refY = sumY/100;
  refZ = sumZ/100;
  refAngle = atan2(refX, refY);
  
  // measures the actual data in a set period and calculate the variance
  // counts the number of occurences that the variances are above the threshold value
  while (millis() - startTime <= PERIOD) {
    axisX = analogRead(A0);
    delay(10);
    axisY = analogRead(A1);
    delay(10);
    axisZ = analogRead(A2);
    angle = atan2(axisX, axisY); 
    varAngle = pow(angle - refAngle, 2);
    if (varAngle > THRESHOLD_XY) {
      countVarXY++;
    }
    varZ = pow(axisZ - refZ, 2); 
    if (varZ > THRESHOLD_Z) {
      countVarZ++;
    } 
  }  
  
  // outputs the wiping states based on the counted number
  if (countVarXY > COUNT_THRESHOLD && countVarZ > COUNT_THRESHOLD) {
    bluetooth.println("Heavy Rain");
  } else if (countVarXY > 0 && countVarZ > 0) {
    bluetooth.println("Light Rain");
  } else {
    bluetooth.println("No Rain");
  }
}

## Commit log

2014-07-14 created 2 new readme in arduino and android
2014-07-14 added images to Arduino readme file
    [Connectedwiper Wiping Waves.xlsx]
2014-07-14 modified readme in arduino
2014-07-14 added photo documentation
    [Connectedwiper Wiping Waves.xlsx]
2014-07-15 modify cad and circuit design
    [BOX.stl, Connected Wiper Box 2.SLDPRT, Connected Wiper Box Insert 2.SLDPRT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]
2014-07-15 modify arduino firmware to On/Off recognition. modify documentation.
2014-07-15 updated till Arduino Section
2014-07-16 modify BOM file
    [BOM.xlsx]
2014-07-16 modify BOM
    [BOM.xlsx]
2014-07-17 correct enclosure link
2014-07-19 added new box design
    [BOX_ver2.stl, INSERT_ver2.stl, LID_ver2.stl]
2014-07-22 added inda BOM
    [India BOM.xlsx]
2014-07-22 update Android Arduino and CAD file as well as documentation
    [INSERT_ver2.stl]
2014-07-23 changed Arduino Readme
2014-07-23 changed Arduino Readme version 2
2014-07-23 re-organized folders
    [BOM.xlsx, India BOM.xlsx]
2014-07-23 update documentation for arduino
2014-07-23 modified BOM for new version box
    [BOM.xlsx, India BOM.xlsx]
2014-07-25 modify BOM. change battery to 110mah
    [BOM.xlsx, India BOM.xlsx]
